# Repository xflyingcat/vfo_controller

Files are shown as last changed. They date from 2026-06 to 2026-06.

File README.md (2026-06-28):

# CAT VFO Controller for Xiegu G90 (STM32 + MT6701)

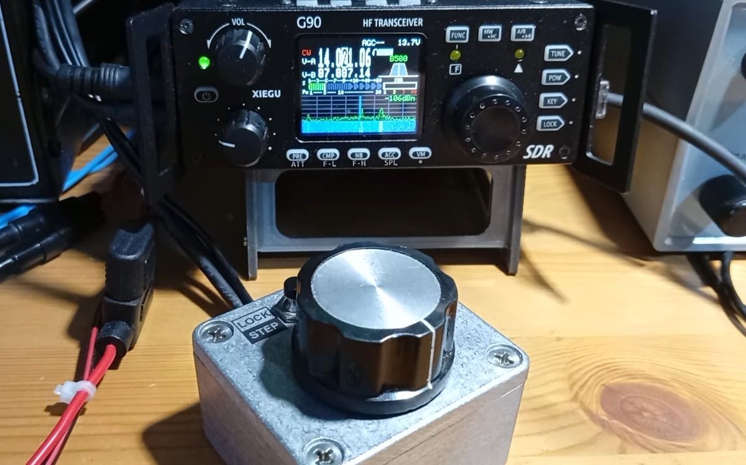
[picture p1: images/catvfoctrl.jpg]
VFO Controller in action
 

📺 [Youtube video: VFO controller in action](https://youtu.be/r33iY527tN8)

---
<details>
<summary><b>Читать на русском языке 🇷🇺</b></summary>

Выносной магнитный валкодер (пульт управления) для КВ-трансивера **Xiegu G90**. 

Проект разработан на базе неблокирующих конечных автоматов (FSM) для воссоздания классического «аналогового» и тактильно приятного ощущения плавной настройки, которого так не хватает штатным энкодерам.

Официальная страница проекта: [https://xflyingcat.ru/catvfoctrl.html](https://xflyingcat.ru/catvfoctrl.html)

### 🚀 Технические особенности реализации (по коду)

* **Оптимизированный тайминг (50 мс) для плавной настройки:** Опрос дельты энкодера происходит с квантом времени **50 мс**. Управляющий пакет отправляется в трансивер только при вращении вала. Это обеспечивает плавность настройки без задержек и исключает перегрузку шины CAT.
* **Магнитный энкодер (MT6701):** Высокоточный бесконтактный датчик, настроенный на фиксированные **400 событий на оборот**. При шаге 10 Гц это дает **4 кГц на оборот**.
* **Аппаратный уровень (STM32F103):** 
    * Квадратурный сигнал энкодера обрабатывается аппаратным таймером `TIM1` в 16-битном режиме.
    * Отправка САТ-команд в трансивер автоматизирована через **DMA** (`DMA1_Channel4`), что освобождает процессор от ожидания отправки байт.
    * Входящий САТ-поток принимается по прерываниям во встроенный кольцевой **FIFO-буфер емкостью 128 байт** с обеспечением атомарности операций при чтении.
* **Фильтрация эха:** На однопроводной шине CI-V контроллер автоматически отфильтровывает собственное эхо отправленных пакетов, реагируя только на входящие сообщения, адресованные мастеру (`THIS_MACHINE_ADDRESS = 0xE0`).
* **Двусторонняя синхронизация (Таймаут 500 мс):** Если ручка пульта статична более 500 мс, контроллер запрашивает текущую частоту у Xiegu G90 (команда `0x25 0x00`). Это предотвращает «скачки» частоты при ручной перестройке на самом трансивере или смене диапазона.
* **Управление шагом (10 Гц / 1 Гц):** Переключение шага происходит при длительном нажатии кнопки LOCK. При возврате с точности 1 Гц на шаг 10 Гц алгоритм автоматически выполняет математическое округление частоты до десятков (`(freq / 10) * 10`), убирая дробный «хвост».

* **Решение проблемы PTT Xiegu G90:** Трансивер не имеет стандартного нормализованного входа PTT (под простую педаль с замыканием линии на землю). Данный пульт полностью решает эту проблему: вы подключаете обычную педаль в гнездо 3.5 мм пульта, при замыкании цепи на землю контроллер переводит трансивер на передачу по шине CAT (команда 0x1C).

* **Защита от залипания PTT (Anti-Stick Watchdog):** Для линии PTT реализован таймер безопасности: при непрерывном удержании передачи более **2 минут**, контроллер принудительно отключает PTT по CAT для защиты выходного каскада трансивера от перегрева.

### 🛠 Аппаратная часть (Hardware)

* **Микроконтроллер:** STM32F103C8T6.
* **Защита цепей:** Гальваническая опторазвязка линии PTT для исключения земляных петель и TVS-супрессоры на линиях RxD/TxD CAT-интерфейса.
* **Механика:** Вал на двух подшипниках с преднатягом.
* **Корпус:** Литой алюминиевый экранированный корпус **Gainta G104** с  гермовводом (дело тут не в герметичности, просто удобный способ ввода кабеля).
* **Кабель:** 

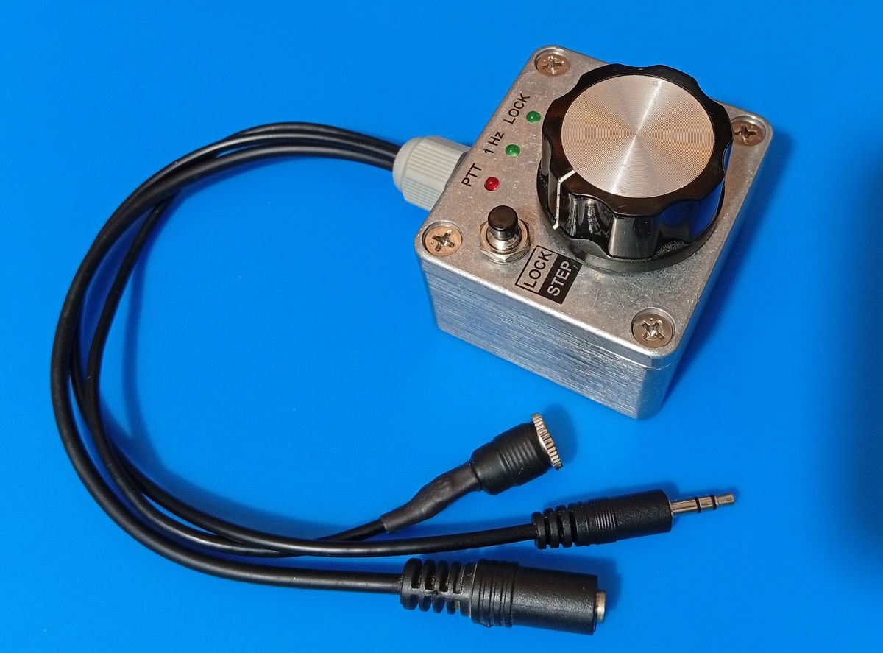
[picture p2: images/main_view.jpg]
Cable Assembly
 

Единый пучок длиной 0.5 м (Питание DC, CAT Jack 3.5мм(штеккер), PTT Jack 3.5мм(гнездо)), введенный через гермоввод.
* **PCB** Проект будущей печатной платы представлен в формате **KiCad**. 

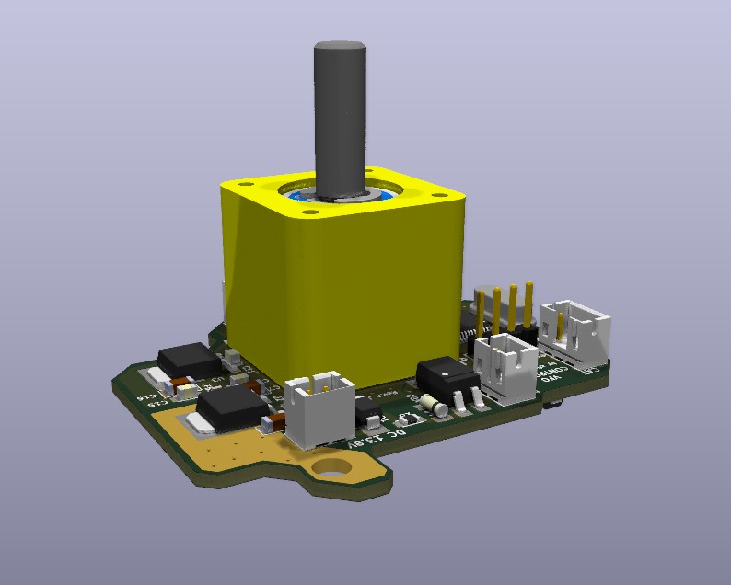
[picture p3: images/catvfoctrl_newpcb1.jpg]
New PCB image
 

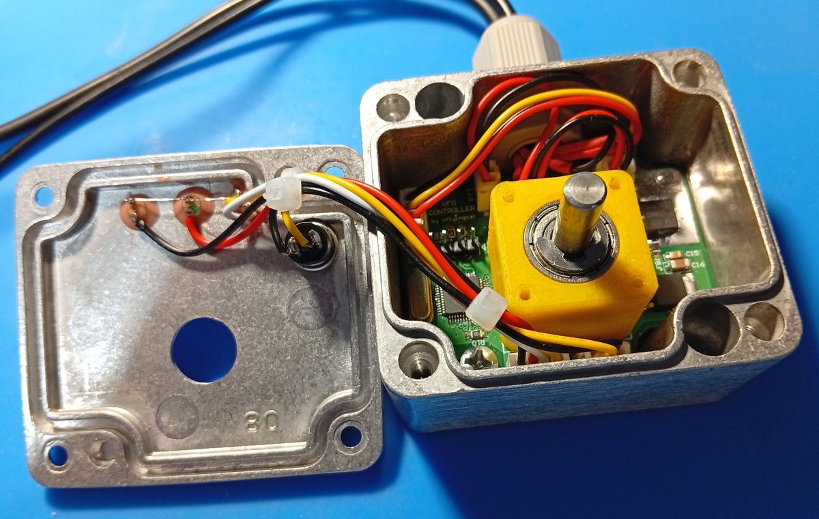
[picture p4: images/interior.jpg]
New PCB image
 

### 💻 Программное обеспечение процесса разработки (Software)

* **Среда разработки:** XPack arm-none-eabi gcc, XPack windows build tools.
* **EDA:** **KiCad**.
---
</details>

<details open>
<summary><b>Read in English 🇬🇧</b></summary>

External VFO controller with magnetic encoder for the **Xiegu G90** HF transceiver based on non-blocking Finite State Machines (FSM).

This project was designed to recreate the classic, tactilely pleasant "analog" feel of smooth tuning, which stock detent encoders lack.

Project Homepage: [https://xflyingcat.ru/catvfoctrl.html](https://xflyingcat.ru/catvfoctrl.html)

### 🚀 Code Architecture

* **Smooth Tuning Response (50 ms):** Encoder delta polling occurs with **50 ms** time quantum. A CAT packet is transmitted only when a physical shaft rotation is detected. This provides absolute tuning smoothness with zero lag and prevents transceiver CAT bus overloading.
* **Magnetic Encoder (MT6701):** High-precision contactless 14-bit sensor configured for a fixed **400 events per revolution**. With a 10 Hz tuning step, this delivers **4 kHz per revolution**.
* **Hardware Level (STM32F103):** 
    * Quadrature encoder signals decoded via hardware `TIM1` timer peripheral in 16-bit mode.
    * Outgoing CAT commands handled smoothly using hardware **DMA** (`DMA1_Channel4`), bypassing CPU wait cycles.
    * Incoming CAT stream parsed via an interrupt-driven ring **FIFO buffer (128 bytes)** with atomic read operation locks.
* **Echo Filtering:** On the single-wire CI-V bus, the controller automatically filters out its own transmitted echo packets by validating the destination address (`THIS_MACHINE_ADDRESS = 0xE0`).
* **Bidirectional Sync (500 ms Timeout):** If the VFO knob is idle for >500 ms, the controller automatically polls the Xiegu G90 for its current frequency (using advanced `0x25 0x00` command). This prevents frequency "jumps" if you change bands directly on the radio.
* **Step Control (10 Hz / 1 Hz):** Step size switching is bound to a long press of the LOCK button. When returning to 10 Hz, the frequency is automatically rounded to the nearest tens of Hz (`(freq / 10) * 10`) to clean up fractional offsets.

* **Xiegu G90 Non-Normalized PTT Fix:** The stock transceiver lacks a standard, normalized PTT input for simple footswitches with ground-keying. This controller completely fixes the issue: you plug any standard pedal into the VFO's 3.5mm jack, press it and the MCU instantly triggers transmission via digital CAT commands (0x1C command).

* **Industrial Grade PTT Safety (Anti-Stick Watchdog):** The PTT line features a built-in safety watchdog: if the PTT remains engaged for more than **2 minutes**, the transmission is forcefully aborted via CAT to protect the radio's PA stage from overheating.

### 🛠 Hardware Specifications

* **MCU:** STM32F103C8T6 (Custom PCB is ready to order).
* **Circuit Protection:** Optocoupler galvanic isolation for the PTT line to break ground loops; low-capacitance TVS suppressor arrays on the CAT RxD/TxD lines.
* **Mechanics:** Custom shaft assembly utilizing dual preloaded ball bearings.
* **Enclosure:** Die-cast aluminum shielded **Gainta G104** housing.
* **Cable Assembly:** 

Cable Assembly 

Integrated 0.5-meter harness (DC Power, CAT 3.5mm Jack/Plug, PTT 3.5mm Jack/Socket) routed via a cable gland.

* **PCB** is presented in **KiCad** format.

New PCB image 

New PCB image 

### 💻 Software Stack

* **IDE:** XPack arm-none-eabi gcc, XPack windows build tools.
* **EDA:** **KiCad**.
</details>

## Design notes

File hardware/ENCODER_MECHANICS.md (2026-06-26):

# Encoder Mechanical Design & Assembly Guide

This document describes the mechanical construction of the precision, zero-backlash rotary encoder mechanical assembly designed for the VFO controller. It provides a robust, heavy, and smooth "analog-like" feel suitable for radio transceiver tuning nodes.

---

## 1. Specifications & Bill of Materials (BOM)

The assembly consists of a 3D-printed housing, two deep-groove ball bearings, a machined steel shaft, and a magnetic sensor coupling.

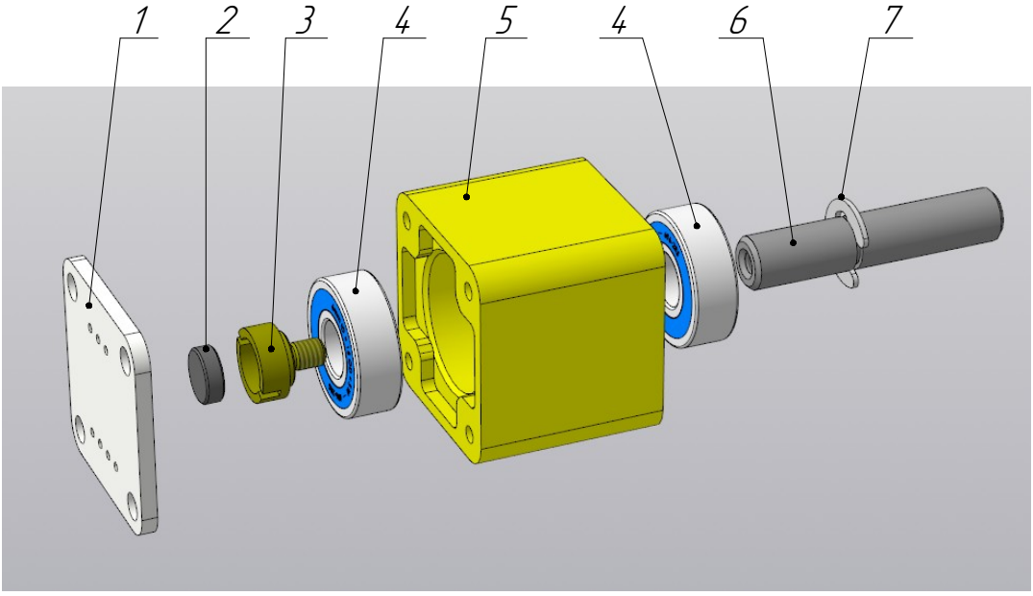
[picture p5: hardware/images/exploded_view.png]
Exploded View


| Item | Description | Material / Specification | Qty |
| :--- | :--- | :--- | :---: |
| **1** | Sensor PCB | MT6701 (or AS5600) break-out board | 1 pc. |
| **2** | Permanent Magnet | Diametrically magnetized, Ø6x2 mm | 1 pc. |
| **3** | Custom Shaped Screw | C3604 (ЛС59) Free-cutting Brass | 1 pc. |
| **4** | Deep Groove Ball Bearing | 6x15x5 mm (696zz) | 2 pcs. |
| **5** | Main Housing | 3D-Printed Plastic (PLA/PETG) | 1 pc. |
| **6** | Encoder Shaft | AISI 1045 (Сталь 45) Calibrated Rod, Ø6 mm | 1 pc. |
| **7** | Retaining Ring | Quick-release E-clip for Ø6 mm shaft | 1 pc. |

---

## 2. Component Drawings & Manufacturing Details

Three custom components need to be fabricated or 3D-printed to complete the assembly:

### Encoder Shaft (Item 6)
Machined from a calibrated **AISI 1045 carbon steel** (Сталь 45) round bar. It features an internal M3 thread for the brass screw and a precise retaining ring groove to lock axial play.

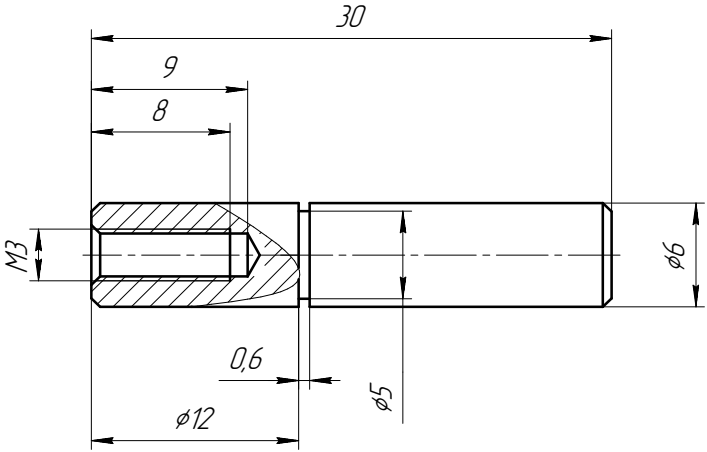
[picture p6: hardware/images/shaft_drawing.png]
Shaft Drawing


### Custom Shaped Brass Screw (Item 3)
Turned from an **C3604 brass** (ЛС59) rod. Brass is selected because it is non-magnetic and will not distort or shield the magnetic field lines directed toward the sensor chip. It includes a dedicated front pocket (lodgement) for the Ø6x2 mm magnet.

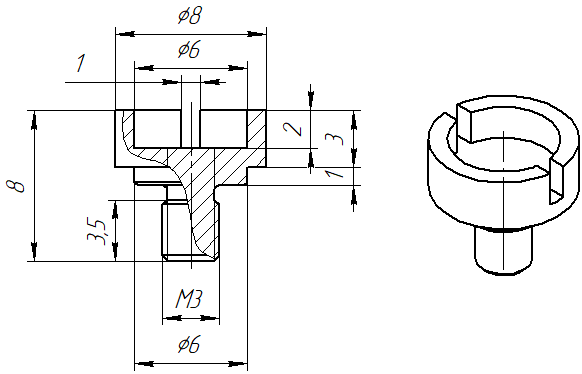
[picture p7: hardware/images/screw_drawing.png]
Custom Screw Drawing


### Housing (Item 5)
The main body is manufactured using additive manufacturing (3D printing). The STL file (`encoder_body.stl`) is available in the repository. 

---

## 3. Step-by-Step Assembly Instructions

To ensure a smooth, backlash-free operation with proper bearing preload, assemble the unit exactly as follows:

1. **Magnet Bonding:**
   * Clean the front pocket of the brass screw (**Item 3**).
   * Glue the diametrically magnetized magnet (**Item 2**) into the pocket using a drop of high-strength cyanoacrylate (super glue) or epoxy. Let it cure completely.

2. **Bearing Installation:**
   * Press-fit the two ball bearings (**Item 4**) into the front and rear recesses of the 3D-printed housing (**Item 5**).
   * *Tip:* For perfect alignment, use a drill press quill acting through a flat mandrel to slide them in square. Avoid heavy hammer impacts that can misalign the outer and inner races.

3. **Shaft Assembly & Preload Adjustment:**
   * Slide the steel shaft (**Item 6**) into the housing through the inner rings of both bearings from the front side.
   * Snap the E-clip retaining ring (**Item 7**) into its groove on the shaft to secure it against the front bearing.
   * Insert and tighten the custom brass screw (**Item 3**) into the rear end of the shaft. Use a custom-made fork/pin wrench plate that fits snugly into the screw slots.
   * Tighten the screw until you achieve the desired **bearing preload**. You should feel a slight, stable "viscosity" during rotation and absolutely zero axial (longitudinal) play. 
   * Once adjusted, back the screw out slightly, apply a drop of threadlocker, and tighten it back down to seal the preload.

4. **Sensor PCB Mounting:**
   * Attach the MT6701 sensor PCB (**Item 1**) to the back face of the housing.
   * Secure it using small pan-head self-tapping screws (ST2.5 x 6 mm). Ensure the sensor IC is perfectly aligned and centered relative to the axis of the rotating magnet.

   ---

> 📌 **Note on Sensor PCB (Item 1):**  
> The breakout board shown as **Item 1** in the exploded view drawing is a generic AliExpress MT6701/AS5600 module and is used **strictly as a mechanical reference** for dimensions and mounting holes.  
> For this project, you should use the custom **`catvfoctrl`** PCB provided in this repository. It perfectly matches the mounting holes of this mechanical assembly but completely eliminates the need for manual hardware modifications (like cutting traces), as the STM32 MCU automatically configures the sensor over I2C at startup.

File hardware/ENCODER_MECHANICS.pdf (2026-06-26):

# Encoder Mechanical Design & Assembly Guide

This document describes the mechanical construction of the precision, zero-backlash rotary encoder mechanical assembly designed for the VFO controller. It provides a robust, heavy, and smooth "analog-like" feel suitable for radio transceiver tuning nodes.

## 1. Specifications & Bill of Materials (BOM)

The assembly consists of a 3D-printed housing, two deep-groove ball bearings, a machined steel shaft, and a magnetic sensor coupling.

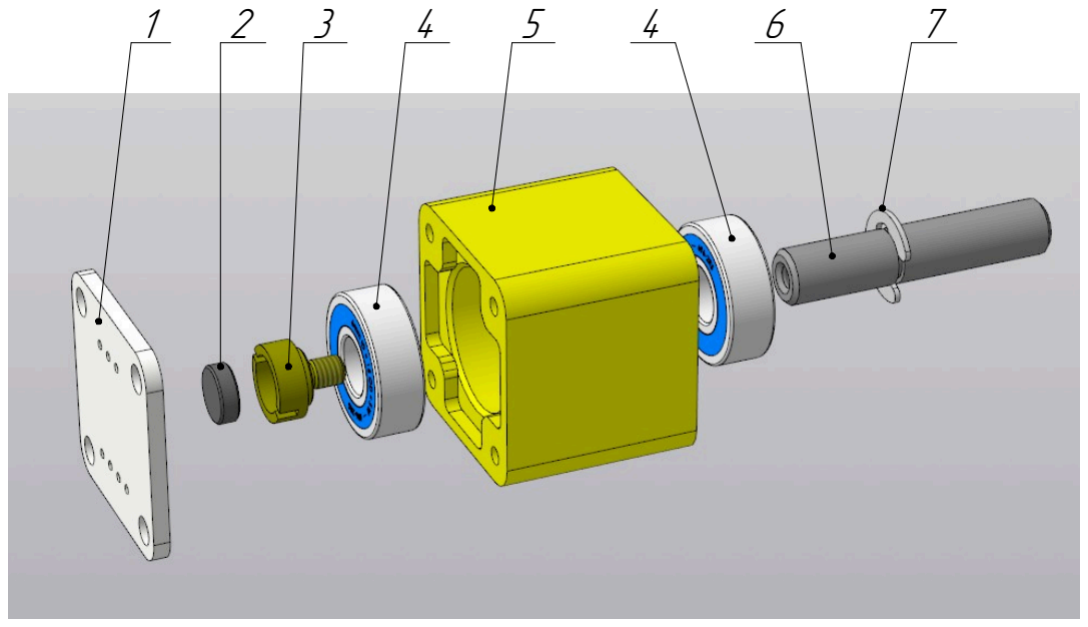
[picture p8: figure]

Item Description | Material / Specification | Qty
1 | Sensor PCB | MT6701 (or AS5600) break-out board | 1 pc.
2 | Permanent Magnet | Diametrically magnetized, Ø6x2 mm | 1 pc.
3 | Custom Shaped Screw | C3604 (ЛС59) Free-cutting Brass | 1 pc.
4 | Deep Groove Ball Bearing 6x15x5 mm (696zz) | 2 pcs.
5 | Main Housing | 3D-Printed Plastic (PLA/PETG) | 1 pc.
6 | Encoder Shaft | AISI 1045 (Сталь 45) Calibrated Rod, Ø6 mm | 1 pc.
7 | Retaining Ring | Quick-release E-clip for Ø6 mm shaft | 1 pc.

## 2. Component Drawings & Manufacturing Details

ENCODER_MECHANICS.md | 2026-06-26

Three custom components need to be fabricated or 3D-printed to complete the assembly:
Encoder Shaft (Item 6)

Machined from a calibrated AISI 1045 carbon steel (Сталь 45) round bar. It features an internal M3 thread for the brass screw and a precise retaining ring groove to lock axial play.

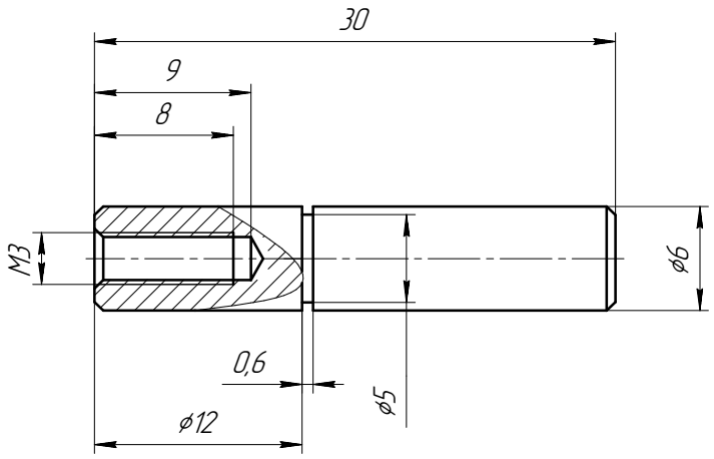
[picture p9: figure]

Custom Shaped Brass Screw (Item 3)

Turned from an C3604 brass (ЛС59) rod. Brass is selected because it is non-magnetic and will not distort or shield the magnetic field lines directed toward the sensor chip. It includes a dedicated front pocket (lodgement) for the Ø6x2 mm magnet.

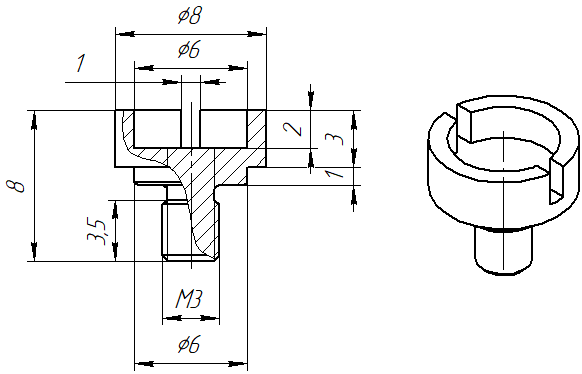
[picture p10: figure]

Housing (Item 5)

The main body is manufactured using additive manufacturing (3D printing). The STL file (encoder_body.stl) is available in the repository.

## 3. Step-by-Step Assembly Instructions

To ensure a smooth, backlash-free operation with proper bearing preload, assemble the unit exactly as follows:

1. Magnet Bonding:

Clean the front pocket of the brass screw (Item 3).
Glue the diametrically magnetized magnet (Item 2) into the pocket using a drop of high-strength cyanoacrylate (super glue) or epoxy. Let it cure completely.
2. Bearing Installation:

Press-fit the two ball bearings (Item 4) into the front and rear recesses of the 3D-printed housing (Item 5).
Tip: For perfect alignment, use a drill press quill acting through a flat mandrel to slide them in square. Avoid heavy hammer impacts that can misalign the outer and inner races.
3. Shaft Assembly & Preload Adjustment:

Slide the steel shaft (Item 6) into the housing through the inner rings of both bearings from the front side.
Snap the E-clip retaining ring (Item 7) into its groove on the shaft to secure it against the front bearing.

Insert and tighten the custom brass screw (Item 3) into the rear end of the shaft. Use a custom-made fork/pin wrench plate that fits snugly into the screw slots.
Tighten the screw until you achieve the desired bearing preload. You should feel a slight, stable "viscosity" during rotation and absolutely zero axial (longitudinal) play.
Once adjusted, back the screw out slightly, apply a drop of threadlocker, and tighten it back down to seal the preload.
4. Sensor PCB Mounting:

Attach the MT6701 sensor PCB (Item 1) to the back face of the housing.
Secure it using small pan-head self-tapping screws (ST2.5 x 6 mm). Ensure the sensor IC is perfectly aligned and centered relative to the axis of the rotating magnet.

📌 Note on Sensor PCB (Item 1):
The breakout board shown as Item 1 in the exploded view drawing is a generic AliExpress MT6701/AS5600 module and is used strictly as a mechanical reference for dimensions and mounting holes.
For this project, you should use the custom catvfoctrl PCB provided in this repository. It perfectly matches the mounting holes of this mechanical assembly but completely eliminates the need for manual hardware modifications (like cutting traces), as the STM32 MCU automatically configures the sensor over I2C at startup.

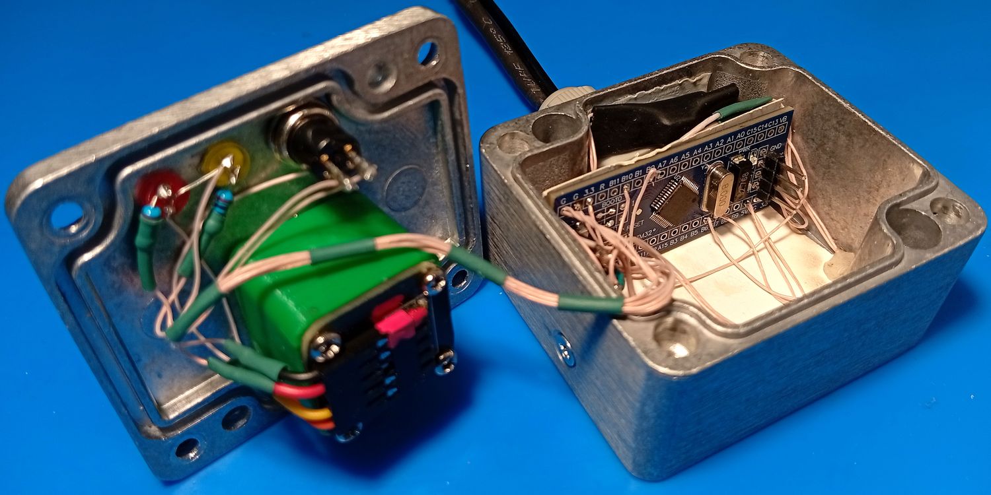
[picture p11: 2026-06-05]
hardware/prototype/prototype.jpg

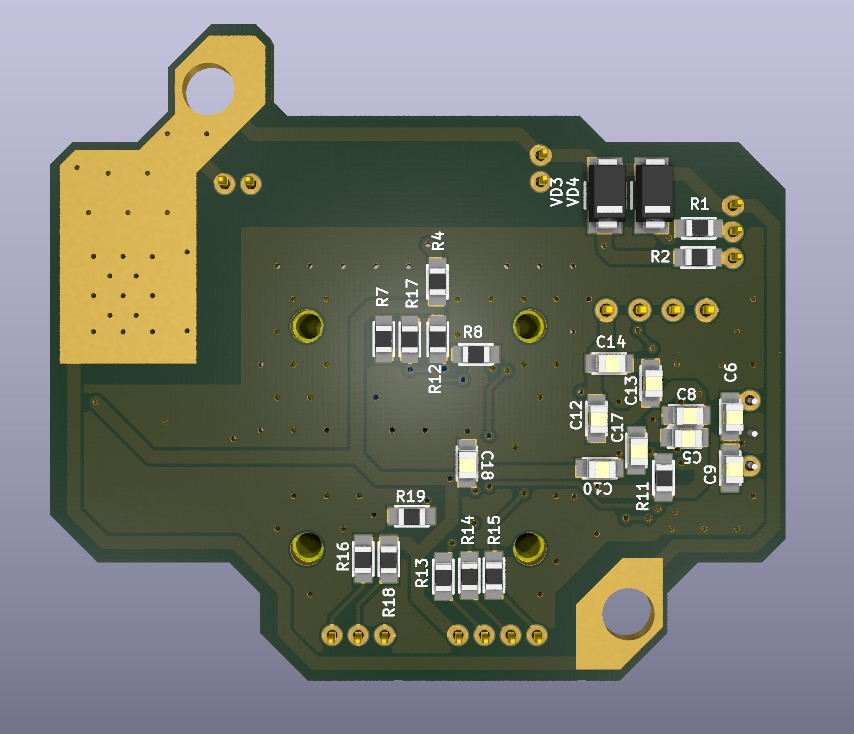
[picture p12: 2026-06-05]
images/catvfoctrl_newpcb3.jpg

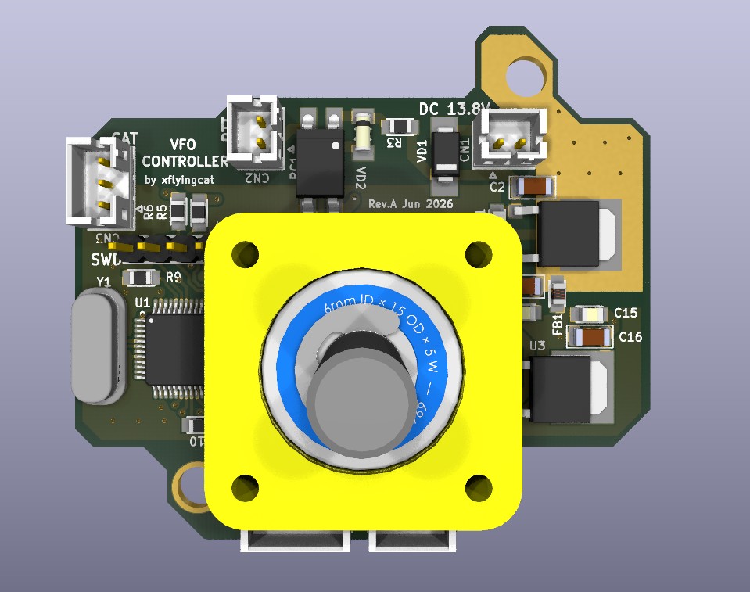
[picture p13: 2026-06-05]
images/catvfoctrl_newpcb.jpg

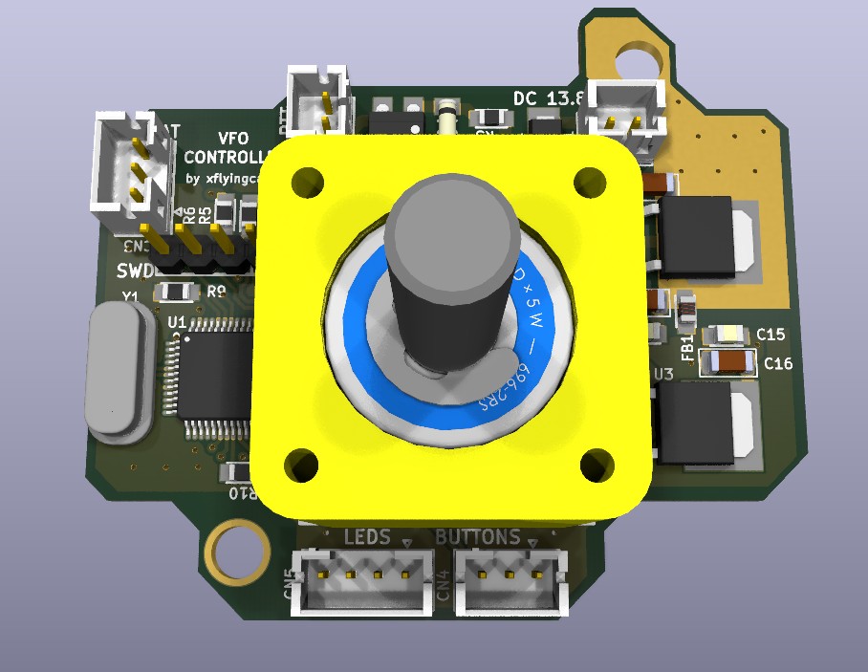
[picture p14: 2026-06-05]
images/catvfoctrl_newpcb2.jpg

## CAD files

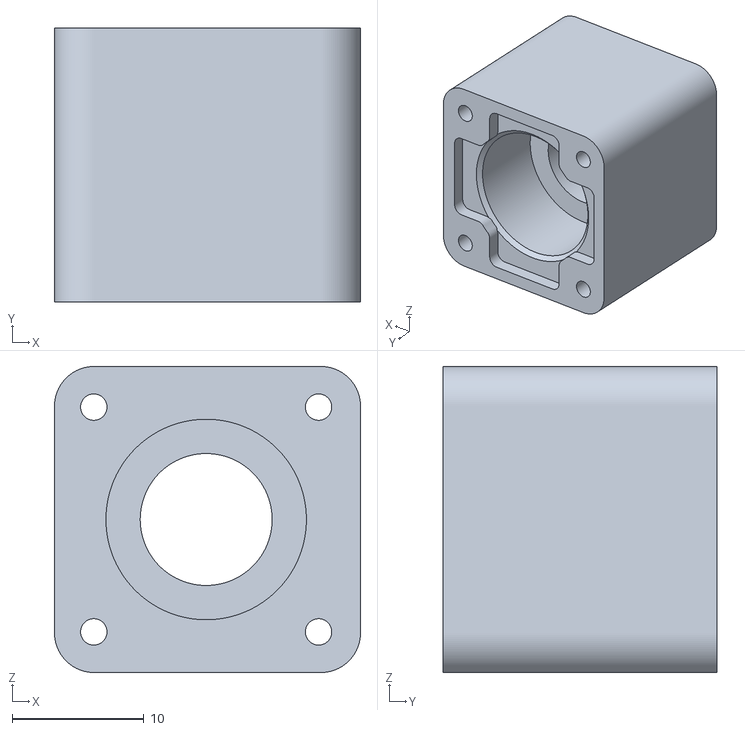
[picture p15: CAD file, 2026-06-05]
hardware/encoder_body.stl
23.2 x 20.8 x 23.2

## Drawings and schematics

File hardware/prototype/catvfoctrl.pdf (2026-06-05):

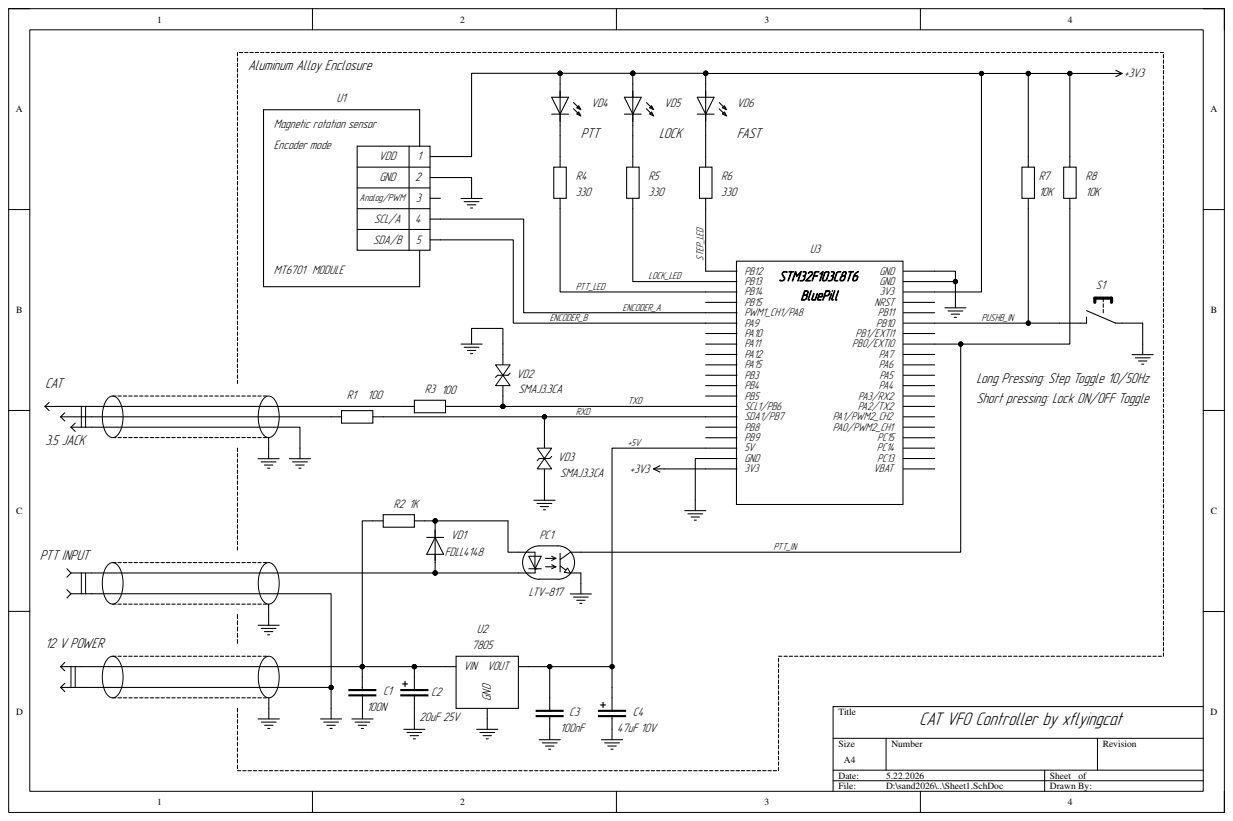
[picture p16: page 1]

Long Pressing: Step Toggle 10/50Hz
Short pressing: Lock ON/OFF Toggle

CAT VFO Controller by xflyingcat

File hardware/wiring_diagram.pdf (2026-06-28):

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

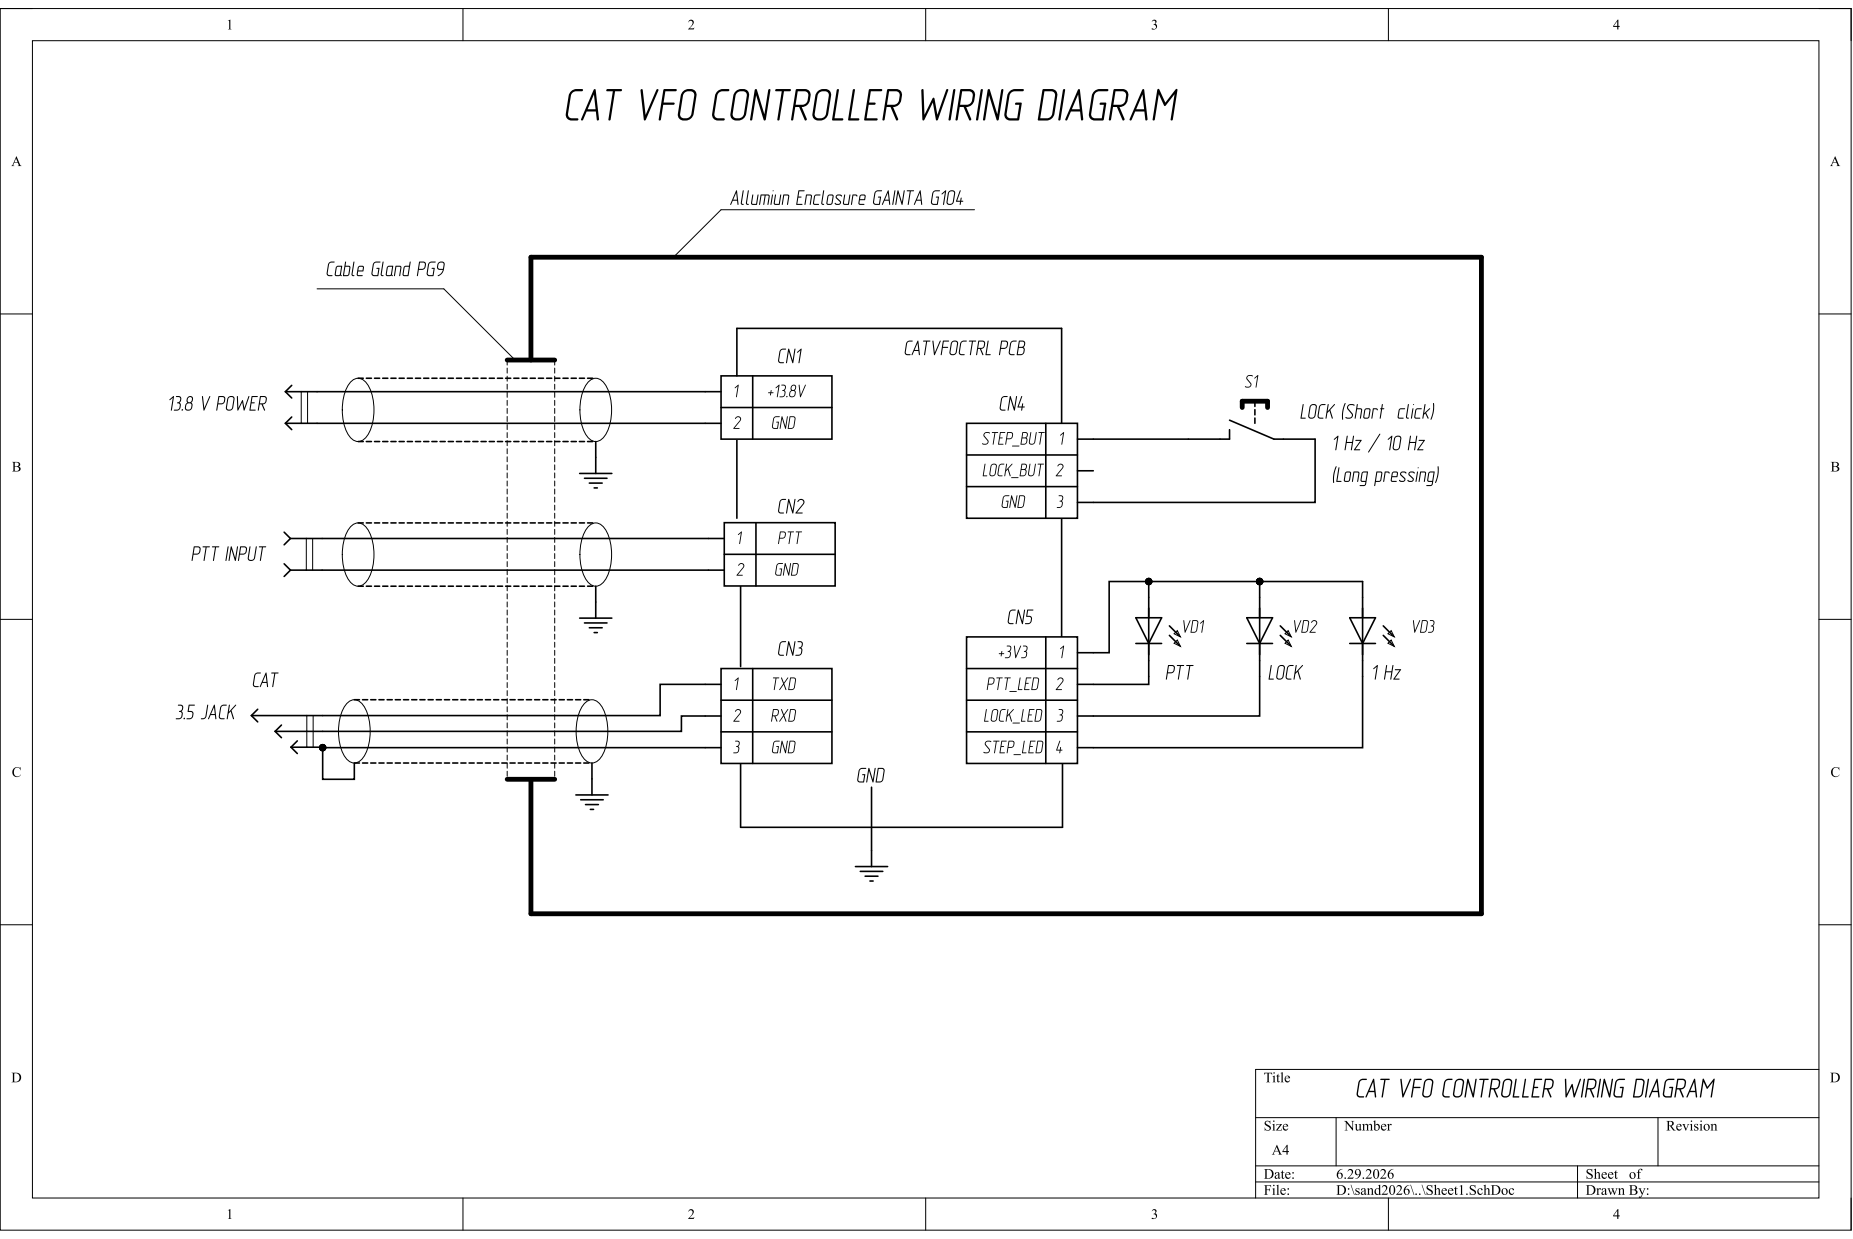
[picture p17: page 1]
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

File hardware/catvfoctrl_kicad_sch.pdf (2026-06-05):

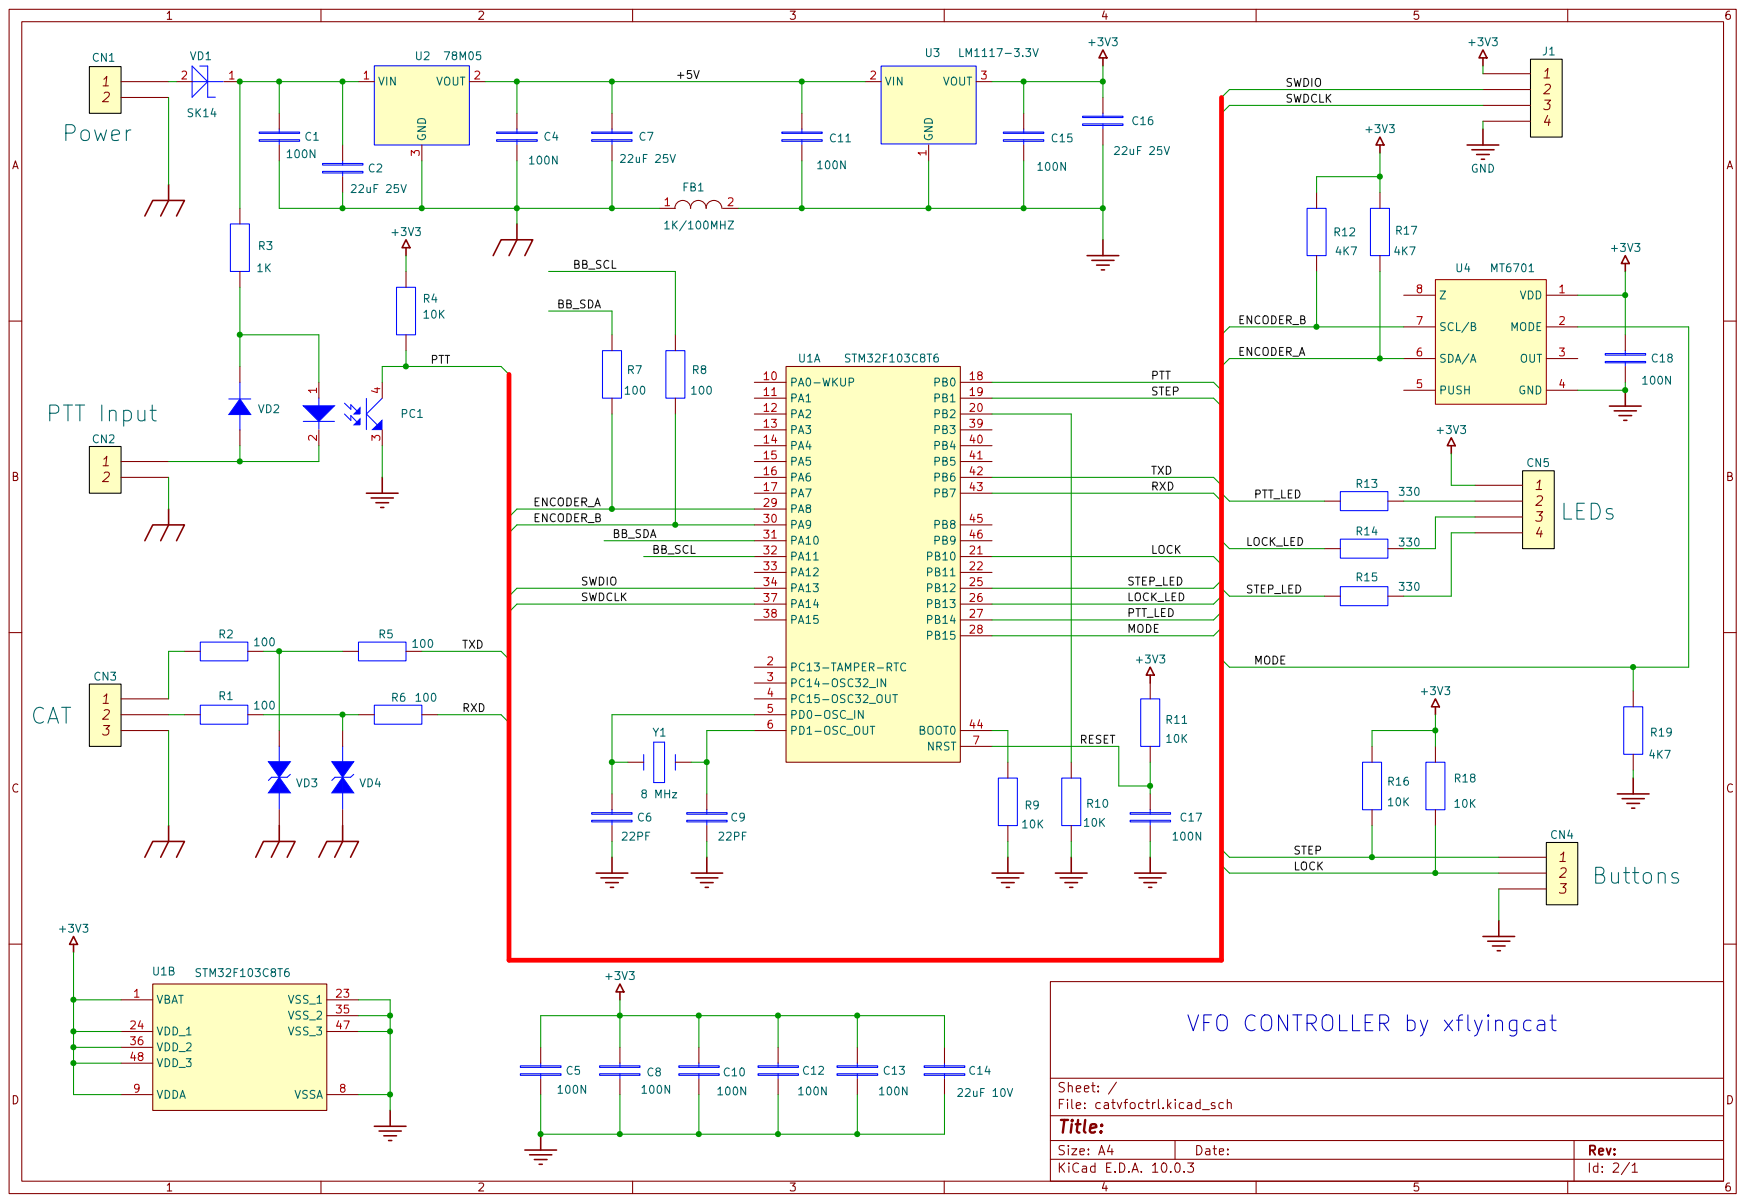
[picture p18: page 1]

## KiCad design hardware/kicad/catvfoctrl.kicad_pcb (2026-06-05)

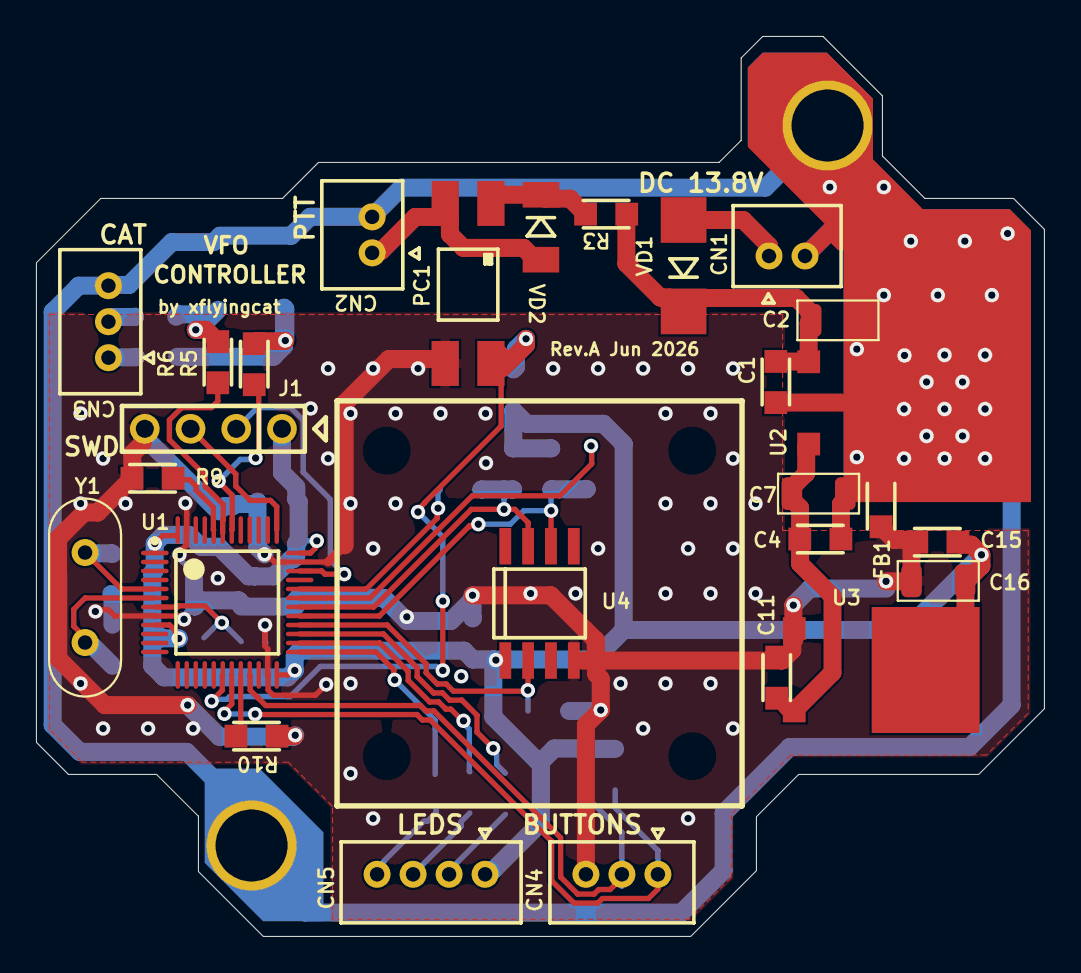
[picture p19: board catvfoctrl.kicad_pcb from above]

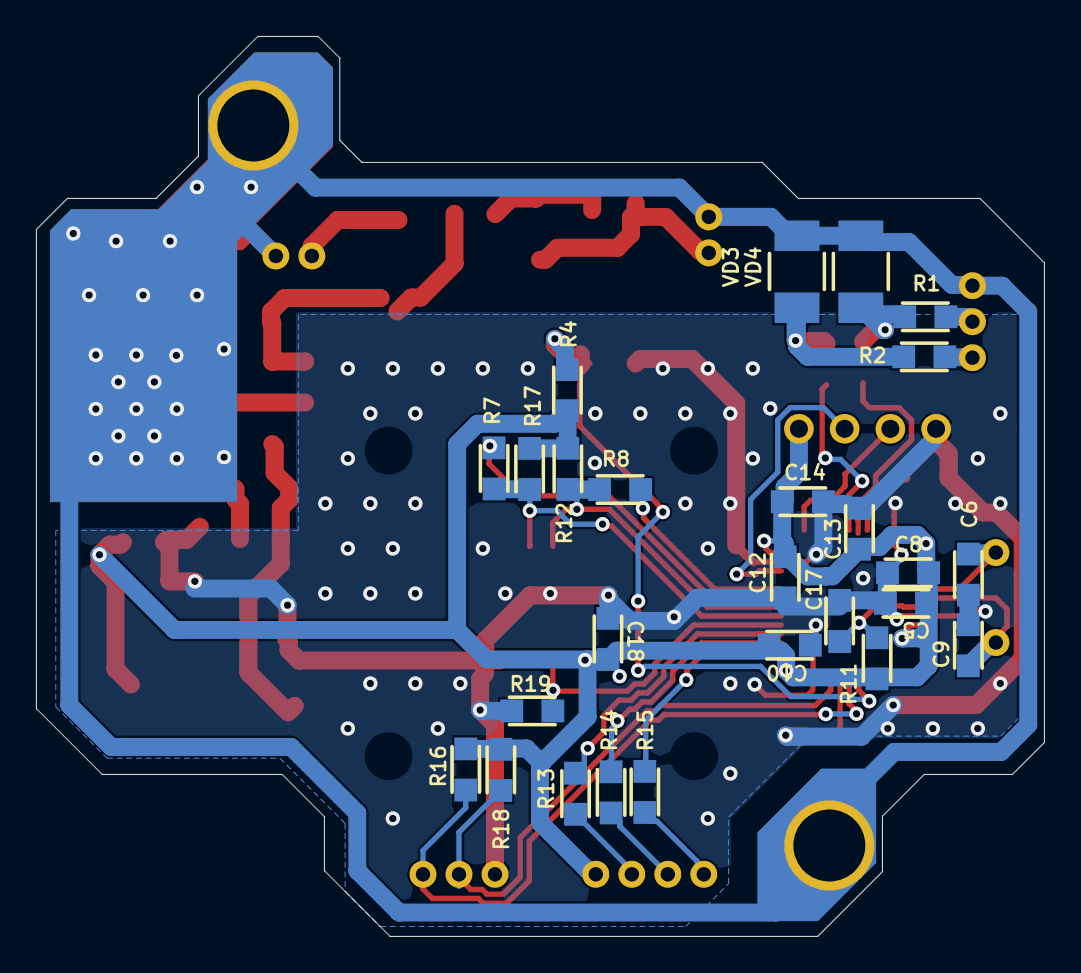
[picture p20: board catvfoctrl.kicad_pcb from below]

Board: 2 copper layers, 56.0 x 50.0 mm, 53 parts (26 on the bottom side), 35 nets.

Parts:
C1, C4, C5, C8, C10, C11, C12, C13, C15, C17, C18: 100N; CAP0805
C2, C7, C16: 22uF 25V; C1206
C6, C9: 22PF; CAP0805
C14: 22uF 10V; CAP0805
CN1: Power; JST2
CN2: PTT input; JST2
CN3: CAT; JST3
CN4: Buttons; JST3
CN5: LEDS; JST4
FB1: 1K/100MHZ; L0805
J1: PLS4; CON1x4
PC1: PC817XNNIP0F; P817_SMD
R1, R2, R5, R6, R7, R8: 100; RES0805
R3: 1K; RES0805
R4, R9, R10, R11, R16, R18: 10K; RES0805
R12, R17, R19: 4K7; RES0805
R13, R14, R15: 330; RES0805
U1: STM32F103C8T6; STM-LQFP48_L
U2: 78M05; SOT252
U3: LM1117-3.3V; SOT252
U4: MT6701
VD1: SK14
VD2: FDLL4148; MLL34
VD3, VD4: SMBJ5.0A-E3/52 UNIPOLAR; SMA
Y1: 8 MHz; QUARTZ_TH

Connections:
+3V3: C5.1, C8.1, C10.1, C12.1, C13.1, C14.1, C15.1, C16.1, C18.1, CN5.1, J1.1, R4.2, R11.2, R12.2, R16.2, R17.2, R18.2, U1.1, U1.9, U1.24, U1.36, U1.48, U3.3, U4.1
+5V: C4.1, C7.1, C11.1, U2.2, U3.2
BB_SCL: R8.2, U1.32
BB_SDA: R7.2, U1.31
ENCODER_A: R7.1, R17.1, U1.29, U4.6
ENCODER_B: R8.1, R12.1, U1.30, U4.7
FG: C1.2, C2.2, C4.2, C7.2, CN1.2, CN2.2, CN3.3, FB1.1, U2.3, VD3.2, VD4.2
GND: C5.2, C6.2, C8.2, C9.2, C10.2, C11.2, C12.2, C13.2, C14.2, C15.2, C16.2, C17.2, C18.2, CN4.3, FB1.2, J1.4, PC1.3, R9.1, R10.1, R19.1, U1.8, U1.23, U1.35, U1.47, U3.1, U4.4
LOCK: CN4.2, R18.1, U1.21
LOCK_LED: R14.1, U1.26
MODE: R19.2, U1.28, U4.2
NetC1_1: C1.1, C2.1, R3.1, U2.1, VD1.1
NetC6_1: C6.1, U1.5, Y1.2
NetC9_1: C9.1, U1.6, Y1.1
NetCN1_1: CN1.1, VD1.2
NetCN2_1: CN2.1, PC1.2, VD2.1
NetCN3_1: CN3.1, R2.1
NetCN3_2: CN3.2, R1.1
NetCN5_2: CN5.2, R13.2
NetCN5_3: CN5.3, R14.2
NetCN5_4: CN5.4, R15.2
NetPC1_1: PC1.1, R3.2, VD2.2
NetR1_2: R1.2, R6.1, VD4.1
NetR2_2: R2.2, R5.1, VD3.1
NetR9_2: R9.2, U1.44
NetR10_2: R10.2, U1.20
PTT: PC1.4, R4.1, U1.18
PTT_LED: R13.1, U1.27
RESET: C17.1, R11.1, U1.7
RXD: R6.2, U1.43
STEP: CN4.1, R16.1, U1.19
STEP_LED: R15.1, U1.25
SWDCLK: J1.3, U1.37
SWDIO: J1.2, U1.34
TXD: R5.2, U1.42

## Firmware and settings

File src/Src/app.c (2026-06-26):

#include "includes.h"

extern TIM_HandleTypeDef htim1;

int ptt_flag = 0;
int lock_flag = 0;
uint32_t freq = 7012340;
int step_value = 10; // default step 10Hz

int32_t get_delta(void);

void setup(void)
{

  mt6701_init();
  //mt6701_eeprom_check_and_burn();
  mt6701_configure(100, 1);
  mt6701_deinit();   
  
  HAL_TIM_Encoder_Start(&htim1, TIM_CHANNEL_ALL);
  HAL_GPIO_WritePin(GPIOB, GPIO_PIN_12, GPIO_PIN_SET);
  HAL_GPIO_WritePin(GPIOB, GPIO_PIN_13, GPIO_PIN_SET);
  HAL_GPIO_WritePin(GPIOB, GPIO_PIN_14, GPIO_PIN_SET);
}

void loop(void)
{
  static uint32_t _50ms,_10ms, startup_flag = 0, to_timer = 0;
  uint32_t delta;
  if(startup_flag == 0)
  {  
     // Executed once during startup
     send_freq_request(); // Request the current transceiver frequency
                          //  for sychronization  
    _50ms = HAL_GetTick() + 50; // Initialize 50ms interval
    _10ms = HAL_GetTick() + 10; // Initialize 10ms interval
     startup_flag = 1;
  }   
    /* Task #1 Receiving data from transceiver using CAT protocol */
    cat_data_input_processing(); // CAT protocol FSM (see FSM callback:
                                 // cat_event())   
  

    /* Task #2 Keys short/Long pressing detecting, debounce */
    if(HAL_GetTick() > _10ms) // We've had the 10ms interval triggered again
    {
      _10ms = HAL_GetTick() + 10; // maintaining an interval of 10 mS   
    
       keypad_processing(); // Keypad FSM (see FSM callbacks:
                            // key_just_pressed_event(),
                            // key_just_released_event(),
                            // key_long_pressing_event())
    }
    
    
    /* Task #3 Encoder processing, send data to transceiver */
    if(HAL_GetTick() > _50ms) // We've had the 50ms interval triggered again
    {
      _50ms = HAL_GetTick() + 50; // maintaining an interval of 50 mS 

      // We read how many encoder pulses the timer 
      // has counted during a 50 ms interval.
      delta = get_delta();
      if(delta)
      {
        to_timer = 0; // restart time out timer
        freq += delta*step_value; // updated frequency value
        send_freq(freq); // update transceiver frequency by CAT
      }
      else
      { // no encoder rotation - no delta
        if(++to_timer >= 10) // idle timer for 500ms
        {  // timed_out
           to_timer = 0;
           // request to get the current transceiver
           // frequency for synchronization
           send_freq_request();  
        }
      }
    }
}


void cat_event(int ev, void *data)
{
   switch(ev)
   {
     case CAT_EVENT_ACK:
     break;
     
     case CAT_EVENT_NAK:
     break;
     
     case CAT_EVENT_FREQ_RCVD:
       freq = (uint32_t)data;
     break;
   }
}

void key_just_pressed_event(int i)
{
  switch(i)
  {
     case PTT:
       ptt_flag = 1;
       // PTT LED turn on
       HAL_GPIO_WritePin(GPIOB, GPIO_PIN_14, GPIO_PIN_RESET);
       ptt_send(1);
       break;

    case STEP:

       
       break;

    case LOCK:

         
       break;
  }
}

void key_just_released_event(int i)
{
  switch(i)
  {
     case PTT:
       ptt_flag = 0;
       ptt_send(0);
       // PTT LED turn off
       HAL_GPIO_WritePin(GPIOB, GPIO_PIN_14, GPIO_PIN_SET);
       break;

    case STEP:
       break;

    case LOCK:
         lock_flag ^= 1;
         // Lock LED 
         HAL_GPIO_WritePin(GPIOB, GPIO_PIN_13, (GPIO_PinState)!(lock_flag == 1));    
       break;
  }
}

void key_long_pressed_event(int i)
{
  switch(i)
  {
     case PTT:
       ptt_flag = 0;
       ptt_send(0);
       // PTT LED turn off
       HAL_GPIO_WritePin(GPIOB, GPIO_PIN_14, GPIO_PIN_SET);       
       break;

    case STEP:
       break;

    case LOCK:
       if(step_value == 10)
       {
         step_value = 1;
         // 1 Hz LED  turn on
         HAL_GPIO_WritePin(GPIOB, GPIO_PIN_12, GPIO_PIN_RESET);
       }
       else if(step_value == 1)
       {
         step_value = 10;
         freq = (freq / 10) * 10;
         // 1 Hz LED  turn off
         HAL_GPIO_WritePin(GPIOB, GPIO_PIN_12, GPIO_PIN_SET);
       }        
       break;
  }
}

int32_t get_delta(void)
{
    static int32_t prev_cntr = 0;
    int16_t curr_cntr = __HAL_TIM_GET_COUNTER(&htim1);
    if(curr_cntr != prev_cntr)
    {
        int32_t delta = prev_cntr - curr_cntr;
        prev_cntr = curr_cntr;

        if(ptt_flag)
           return 0;
        
        if(lock_flag)
           return 0;
        

        if((delta > -1000) && (delta < 1000))
        {
            return delta;
        }
    }
    return 0;
}

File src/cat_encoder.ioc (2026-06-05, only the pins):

Mcu.UserName=STM32F103C8Tx
PA13.Signal=SYS_JTMS-SWDIO
PA14.Signal=SYS_JTCK-SWCLK
PA8.Signal=S_TIM1_CH1
PA9.Signal=S_TIM1_CH2
PB0.Signal=GPIO_Input
PB1.Signal=GPIO_Input
PB10.Signal=GPIO_Input
PB12.Signal=GPIO_Output
PB13.Signal=GPIO_Output
PB14.Signal=GPIO_Output
PB6.Signal=USART1_TX
PB7.Signal=USART1_RX
PD0-OSC_IN.Signal=RCC_OSC_IN
PD1-OSC_OUT.Signal=RCC_OSC_OUT

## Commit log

2026-06-05 Initial commit: full project with firmware, hardware and mechanics
    [catvfoctrl.SCHLIB, catvfoctrl.kicad_pcb, catvfoctrl.kicad_sch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]
2026-06-26 Added Wiring Diagram, Interactive BOM and Gerber files
2026-06-26 Added Encoder_Mechanics.mp/pdf. Moved catvfoctrl_kicad_sch.pdf into hardware folder
2026-06-27 Added images for Encoder Mechanics
2026-06-28 Fixed wiring diagram
